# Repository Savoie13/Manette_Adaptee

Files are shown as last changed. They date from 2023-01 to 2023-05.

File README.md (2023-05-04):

# Manette Adaptée : Jouer sans limite
## Mathis Savoie et Jackob Breton
Ce répertoire GitHub est pour le projet de manette adapté avec l’école du Touret. Nous sommes 2 finissants en technologie de systèmes ordinés et le projet que nous allons tenter de réaliser est de programmer un Arduino Micro pour faire une manette pour des jeux Scratch. Cette manette adaptée permettra aux élèves de l’école du Touret qui ont moins de mobilité de jouer à des jeux vidéo comme leurs camarades. La manette sera composée de gros boutons et joysticks et permettra de brancher divers boutons pour plus de fonctionnalités. La manette comporte aussi un ESP8266 afin de pouvoir, grâce à une interface d’usager WEB, configurer la manette et ses boutons.
MicrosoftTeams-image

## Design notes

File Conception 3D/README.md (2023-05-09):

# Conception 3D
Ce dossier contient les fichiers de la conception 3D de la manette adaptée.
Le fichier Joystick_VFinale.stl est le fichier STL de la version finale du manche du joystick.
Le fichier Joystick_VFinale.gcode est le fichier gcode pour imprimer le joystick sur les imprimantes que
nous retrouvons au Cégep de Sherbrooke.

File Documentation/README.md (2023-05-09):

# Documentation
Ce dossier contient toute la documentation concernant le projet de manette adaptée.
Nous y retrouvons la documentation technique du projet, des PowerPoint de nos présentations orales, notre
participation au concours OsEntreprendre et des schémas que nous avons utilisés pour la documentation.

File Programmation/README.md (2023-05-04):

# Programmation
Ce dossier contient tous les programmes utiles au fonctionnement et à la conception de la manette adaptée. 
Aller voir le README.md dans les différents répertoires afin d'avoir plus d'information. 

Le programme dans le répertoire WriteEEPROM est le premier programme à télécharger dans l'arduino pro micro. Il permet d'installer la configuration par défaut dans l'EEPROM du pro micro.

Par la suite, il faut programmer la dernière version de Full_controllerV(x) dans l'arduino afin d'avoir le programme qui fait fonctionner la manette et réceptionne les JSON envoyé par l'ESP8266.

Le répertoire Code_Serveur_Spiffs contient le code Arduino IDE du L'ESP8266 ainsi que le répertoire "data" qui contient les fichiers nécéssaires pour le fonctionnement du serveur web.

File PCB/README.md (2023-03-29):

# PCB
Ce dossier contient les schémas et PCBs de la manette adaptée

Le répertoire Manette_JM contient le projet KiCad

Le répertoire Manette_JM_Gerber contient les fichiers Gerber afin de l'envoyer à une compagie de fabrication de PCB.

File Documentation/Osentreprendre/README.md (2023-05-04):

# Documentaiton Osentreprendre
C'est la documentation plus marketing du projet. Elle contient entre autre, une affiche de projet et une présentation PowerPoint.

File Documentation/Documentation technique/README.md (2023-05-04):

# Documentation technique
Partie technique de la documentation. Elle contient entre autres, le cahier des charges, le devis technique et le manuel technique

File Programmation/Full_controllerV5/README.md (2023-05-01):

# Full_controllerV5
Ce code est le programme principal du Arduino Pro Micro. Il sert à controller le clavier et la souris d'un ordinateur.
Il permet aussi au Arduino Pro Micro de recevoir des JSON sur son port série pour sa configuration, enregistrer 
ces configurations dans l'EEPROM et de les renvoyer en JSON sur son port série pour confirmer le tout.

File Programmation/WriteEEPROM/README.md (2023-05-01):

# WriteEEPROM
Code qui écrit des données dans l'EEPROM du Arduino Leonardo pour la configuration de base et le fonctionnement du code final full_controllerV5.

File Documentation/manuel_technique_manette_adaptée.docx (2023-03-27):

## Mettre Installation et Opération ensemble : Procédure d’utilisation

## Procédure d’installation

1. Placer la manette de la manière voulue près d’un ordinateur.
2. Brancher le câble USB de la manette dans l’ordinateur.
3. La manette est prête à être utilisé avec les paramètres déjà définis.

## Procédure d’opération

## Procédure de développement.

Voici ce qui est nécessaire pour le développement de la manette adaptée :

- Pour le développement du code du microcontrôleur :
1. Installer la dernière version d’Arduino IDE pour votre ordinateur (Windows, MacOs ou Linux) au site web suivant :

https://www.arduino.cc/en/software

2. Pendant l’installation, accepter toutes les configurations de base.
3. Ouvrir Arduino et créer un nouveau projet dans le menu : fichier > Nouveau.
4. Aller chercher le premier code au :

https://github.com/Savoie13/Manette_Adaptee/blob/main/Programmation/WriteEEPROM/WriteEEPROM.ino

5. Copier et coller ce code dans le nouveau projet et enregistrer ce projet n’importe où.
6. Brancher l’Arduino Leonardo.
7. Dans le menu : Outils > Type de carte : choisir Arduino Leonardo ETH.
8. Dans le menu : Outils > Port : choisir le port sur lequel est branché votre Arduino
9. Téléverser le code avec le bouton de la flèche en haut à gauche de la page. Le code devrait se télécharger en quelques secondes.
10. Maintenant le premier code téléchargé, il faut faire la même chose avec le deuxième code.
11. Refaire les étapes 3 à 9 inclusivement en utilisant le code à l’adresse suivante :

https://github.com/Savoie13/Manette_Adaptee/blob/main/Programmation/Full_controllerV5/Full_controllerV5.ino

12. Une fois ces deux codes téléchargés dans cet ordre les boutons et le joystick de la manette seront fonctionnels.
13. Toutes les informations nécessaires pour la compréhension et le développement des codes microcontrôleur de la manette adaptée sont inscrits dans l’entête de ce dernier. Le code est aussi commenté au complet pour comprendre la raison de la présence de chaque ligne dans ce dernier.
- Pour le développement du code site Web et point d’accès :

## Liste de matériel et coûts

Composants | Prix | Lien
- Microcontrôleur Micro Atmega32U4 | $15.49 | - Arduino Pro Micro (https://www.amazon.ca/ATmega32U4-Development-Microcontroller-Leonardo-Bootloader/dp/B07WPCLF8Y)
- Carte de développement WI-FI ESP8266 | $12.99 | - ESP8266 (https://addison-electronique.com/produits/pieces-et-composantes/electricite-electronique/genuino-electricite-electronique/carte-de-d-veloppement-wifi-mcu-esp8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)
- Joystick | $19.95 | - Joystick (https://www.digikey.ca/en/products/detail/adafruit-industries-llc/3102/6152821)
- 9 boutons de style arcade | $39.98 | - Boutons (https://www.amazon.ca/-/fr/boutons-poussoirs-lumineux-darcade-monnaie/dp/B01M7PNCO9)
- Boitier du joystick | $13.99 | - Boite joystick (https://www.amazon.ca/-/fr/LeMotech-imperm%C3%A9able-poussi%C3%A8res-%C3%A9lectriques-universels/dp/B075DJDT99)
- Boitier des boutons | $19.79 | - Boite boutons (https://www.amazon.ca/-/fr/LeMotech-imperm%C3%A9able-poussi%C3%A8res-%C3%A9lectriques-universels/dp/B075DJQJVY)
- PCB | $02.00 | - JLC PCB (https://jlcpcb.com/)
- Matériel électronique (connecteurs, fil, résistances, etc.) | $25.00

Total : $149.19

## Schéma électrique

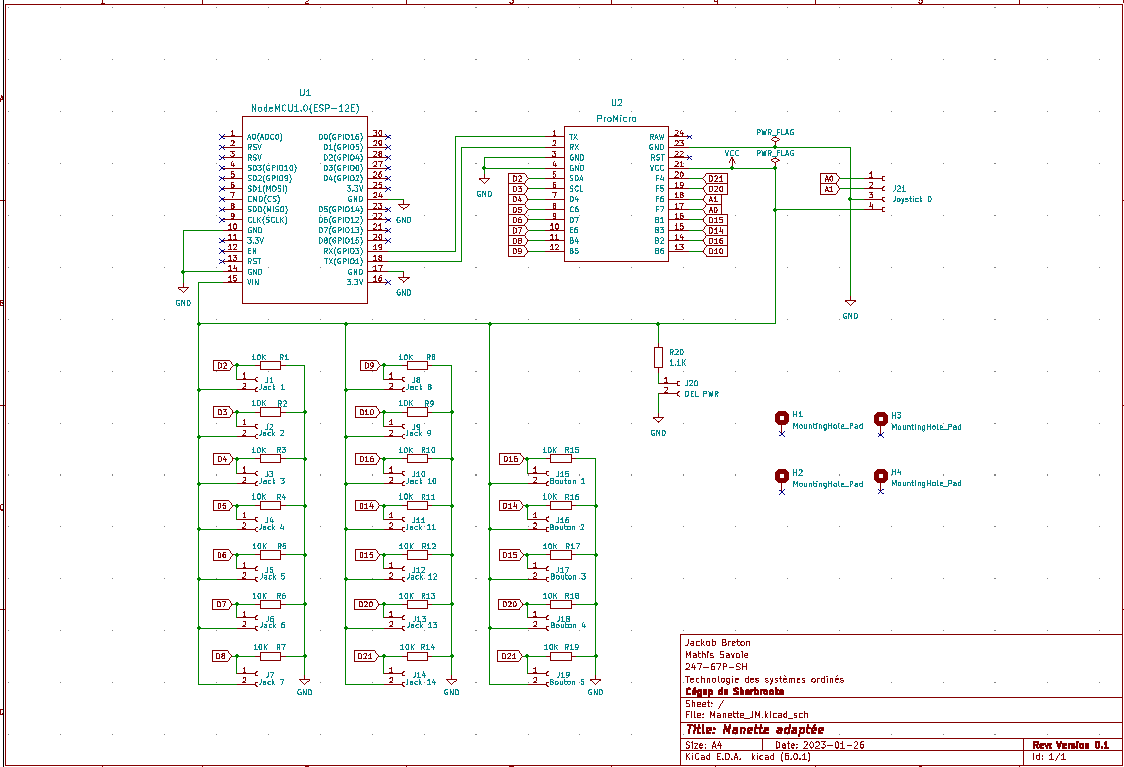
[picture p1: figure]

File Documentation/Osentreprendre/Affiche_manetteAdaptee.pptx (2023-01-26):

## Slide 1

Manette adaptée

JOUER SANS LIMITE

Projet pour l’école du Touret

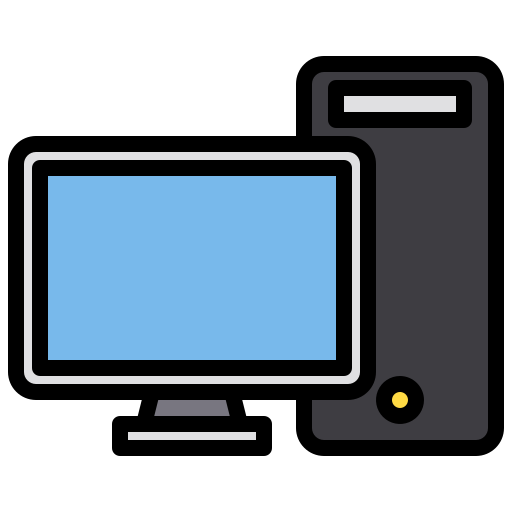
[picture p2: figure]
Pc - Free computer icons

Conçu pour les personnes avec une motricité réduite

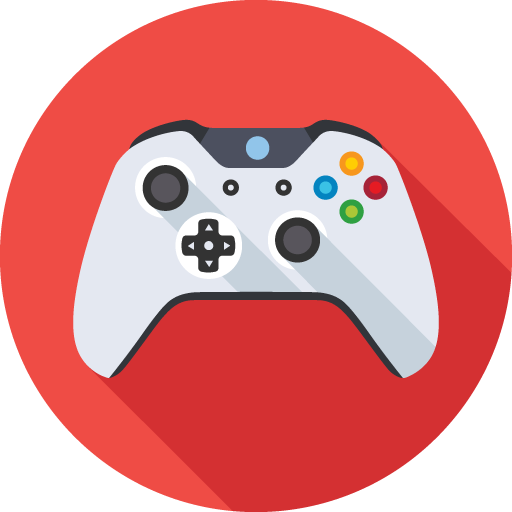
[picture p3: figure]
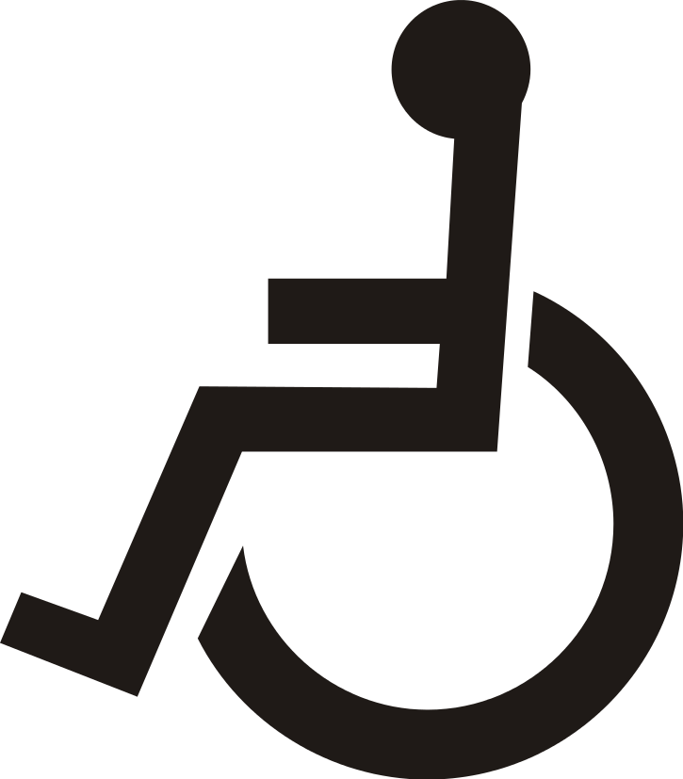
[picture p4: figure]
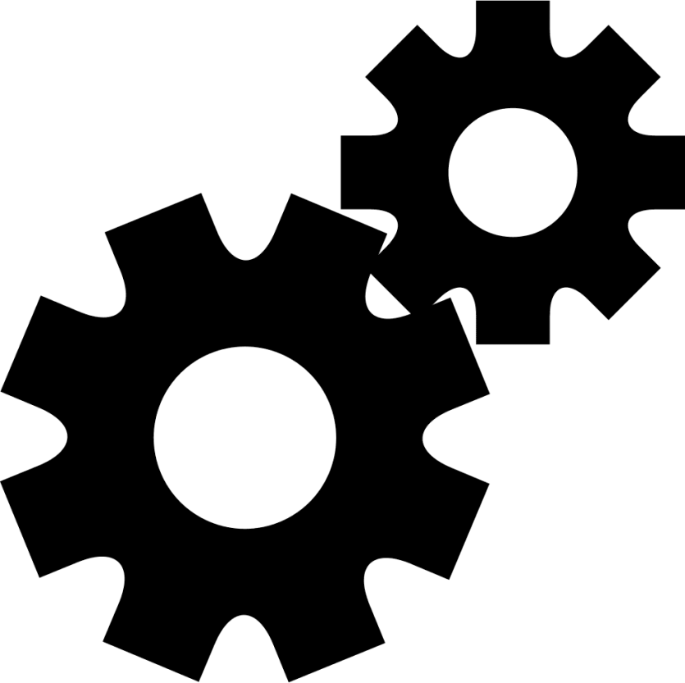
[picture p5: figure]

Configuration de la manette à l’aide d’une interface Web

Compatible PC

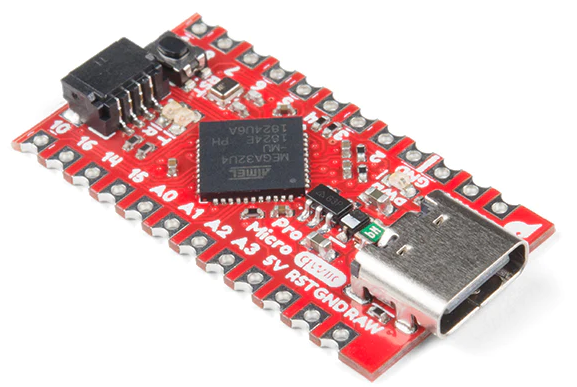
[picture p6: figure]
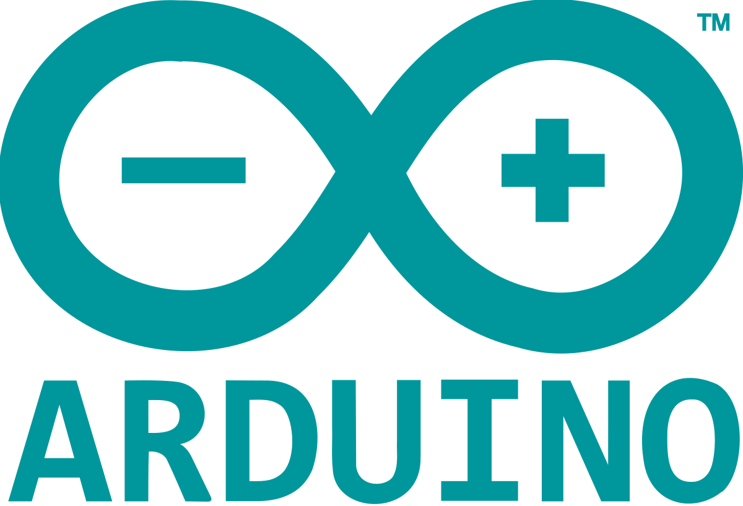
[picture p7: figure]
Arduino — Wikipédia
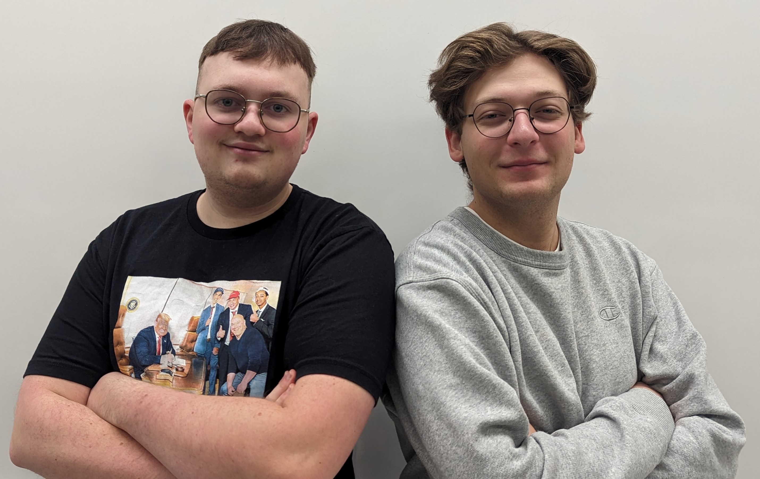
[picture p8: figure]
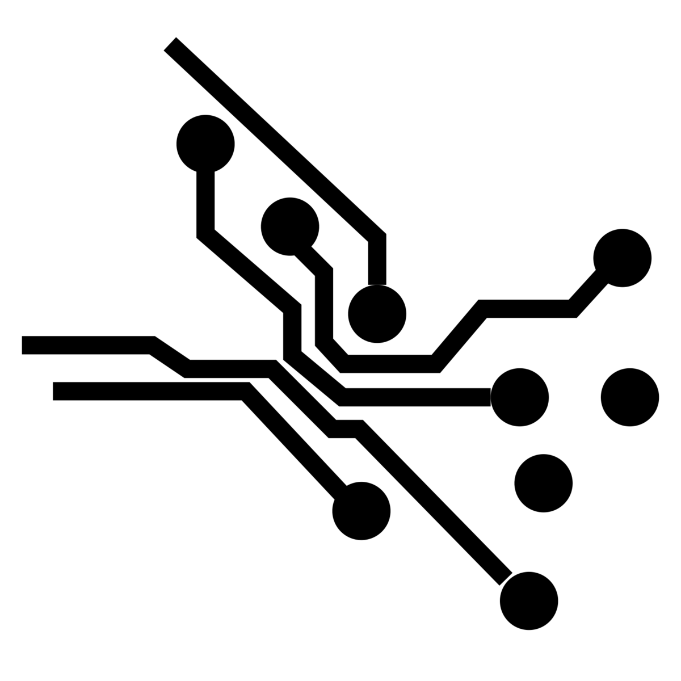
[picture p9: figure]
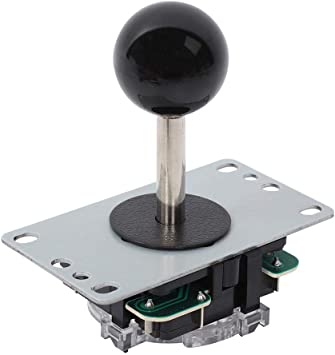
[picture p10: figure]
Manette USB pour PC, pour jeu d'arcade Jeu de combat simple Joystick Jeu de bricolage PC Pièces Machine Arcade Jeu Bouton et Joystick Simple Rocker pour Raspberry Pi), Zopsctg3irp8q4g-11 : Amazon.ca: Jeux
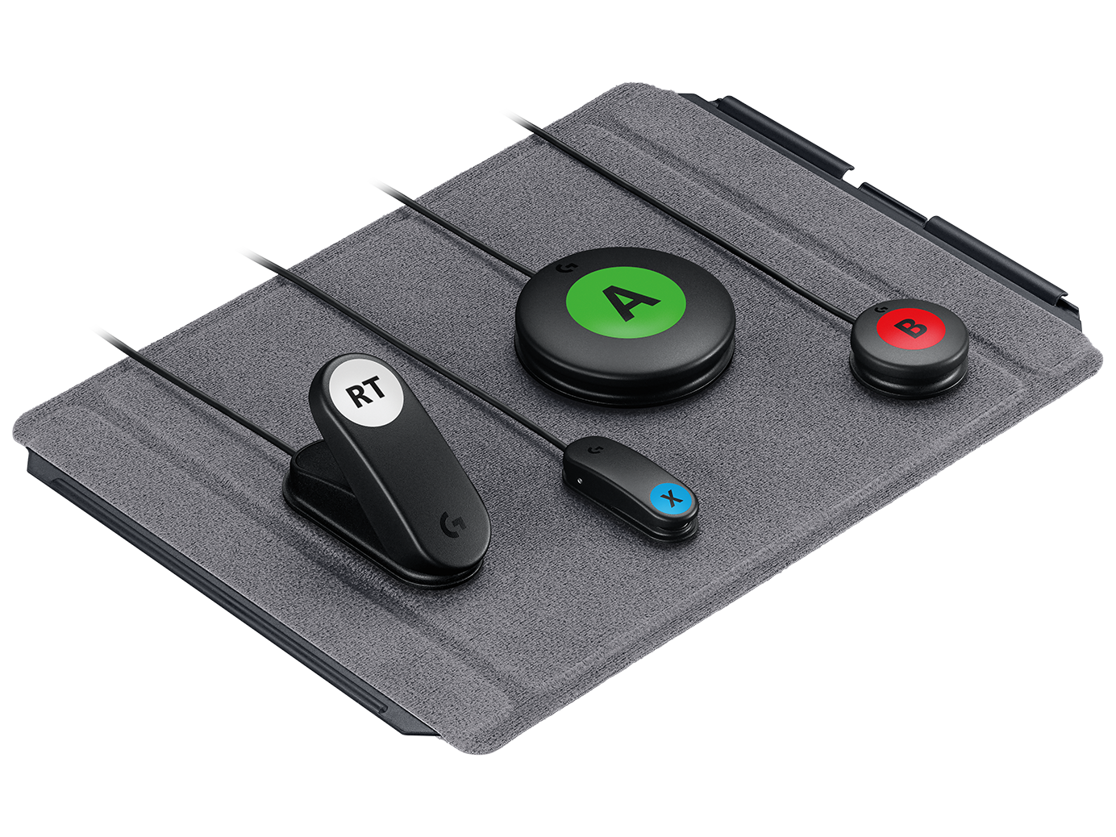
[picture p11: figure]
Kit de jeu Logitech G Adaptive pour la manette Xbox Adaptive

Jackob Breton

Mathis Savoie

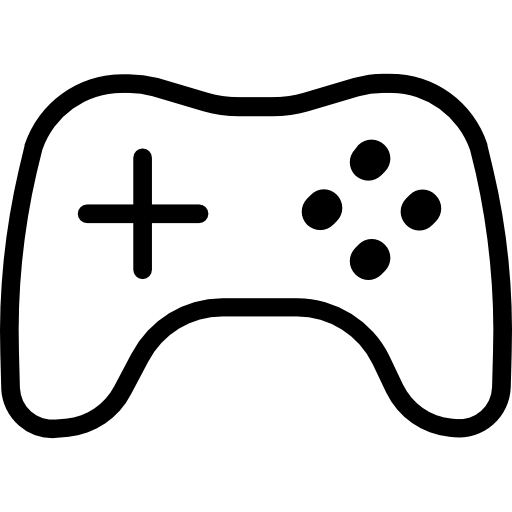
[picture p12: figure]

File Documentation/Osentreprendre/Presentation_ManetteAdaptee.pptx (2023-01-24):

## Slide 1

C’EST QUOI ?

MANETTE ADAPTÉE
JOUER SANS LIMITE

Présenté par Mathis Savoie et Jackob Breton

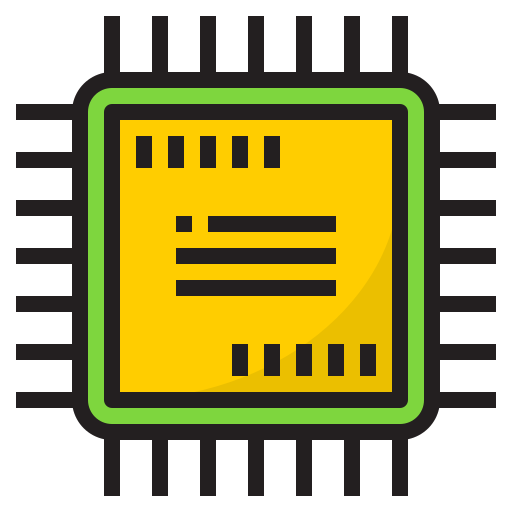
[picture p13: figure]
Processor - Free computer icons

- Rencontre avec le client
- Planification
- Conception du circuit électrique
- Sélection des empruntes
- Élaboration du circuit imprimé
- Envoie des fichiers de conception

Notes: JACKOB
Nos nom + génie électrique + nom du projet

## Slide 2

C’EST POUR QUI ?

C’EST QUOI ?

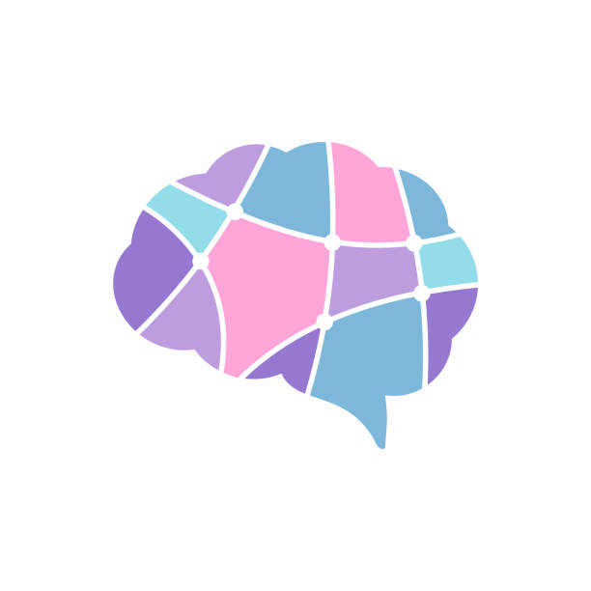
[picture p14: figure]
5,200 Intellectual Disability Illustrations & Clip Art - iStock
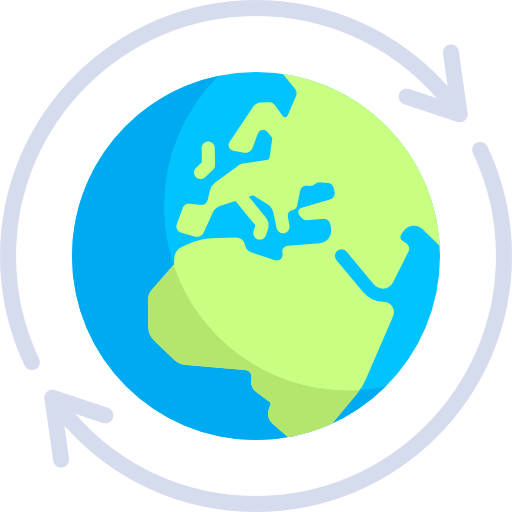
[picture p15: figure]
Worldwide - Free signs icons

MANETTE ADAPTÉE
JOUER SANS LIMITE

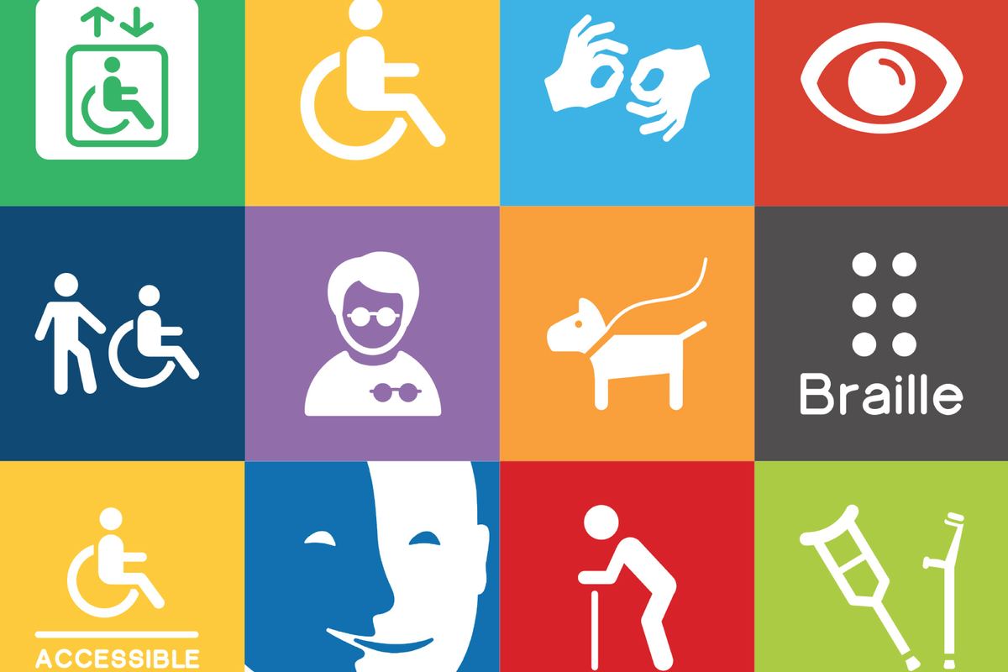
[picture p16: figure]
Différents types de handicaps - Département des Alpes-Maritimes

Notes: JACKOB
Manette adaptée pour les personnes avec difficulté motrice
Composé de gros boutons et joysticks de type arcade
Elle sera beaucoup plus grosse qu’une manette normal afin de facilité son utilisation

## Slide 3

C’EST QUOI ?

C’EST POUR QUI ?

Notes: MATHIS
- Les personnes ayant des déficiences motrices et/ou mentales qui donc manquent de dextérité et/ d’agilité
- //Mentales car elle ralentie les actions motrices (pense au mouvement avant de le faire)
- Quand même pour tous : enfants et adultes de partout dans le monde.
- Pour l’apprentissage et le développement, mais aussi pour leur inclusion avec les autres. (développer)

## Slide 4

COMMENT JOUER ?

LES ÉCOLES

PERSONNES À MOBILITÉ RÉDUITE

LES CENTRES ADAPTÉS

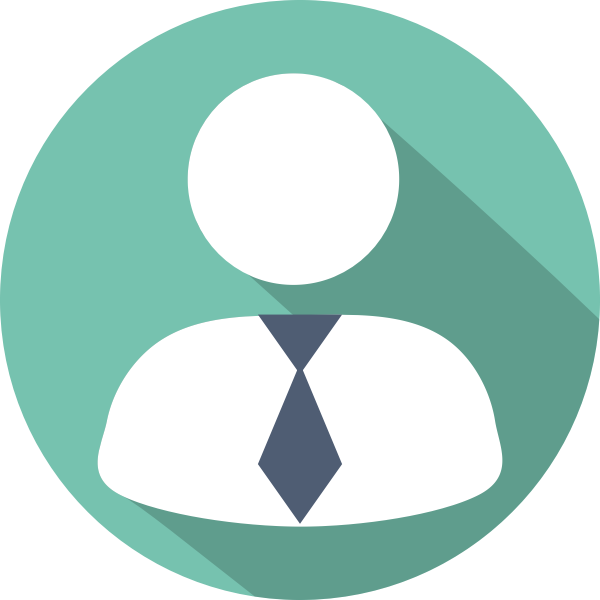
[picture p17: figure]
Client icon | Free SVG

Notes: MATHIS
- Suffit de brancher la manette dans un ordinateur pour l’utiliser.
- Pour plus d’options il sera possible de changer la configuration des boutons sur une application web.

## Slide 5

C’EST POUR QUI ?

NOS CLIENTS

Mini-ordinateur | 33$
Joystick | 32$
Boutons | 20$
Boîtier | 10$
Électronique | 35$
Total | 130$

LES ÉCOLES

PERSONNES À MOBILITÉ RÉDUITE

LES CENTRES ADAPTÉS

COMMENT JOUER ?

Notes: JACKOB
- Pour l’instant notre projet est en collaboration avec l’école du Touret (explique c’est quoi).
- Nos clients ciblés sont les personnes avec mobilité réduite.
- Par la suite, les écoles et les centres adaptés pour aidé à l’apprentissage des élèves handicapé.

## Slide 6

NOS CLIENTS

LES COÛTS

± 130$CAD
(équipements compris)

Mini-ordinateur | 33$
Joystick | 32$
Boutons | 20$
Boîtier | 10$
Électronique | 35$
Total | 130$

LES ÉCOLES

PERSONNES À MOBILITÉ RÉDUITE

LES CENTRES ADAPTÉS

130$CAD + taxes
(rien compris)

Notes: MATHIS

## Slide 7

130$CAD

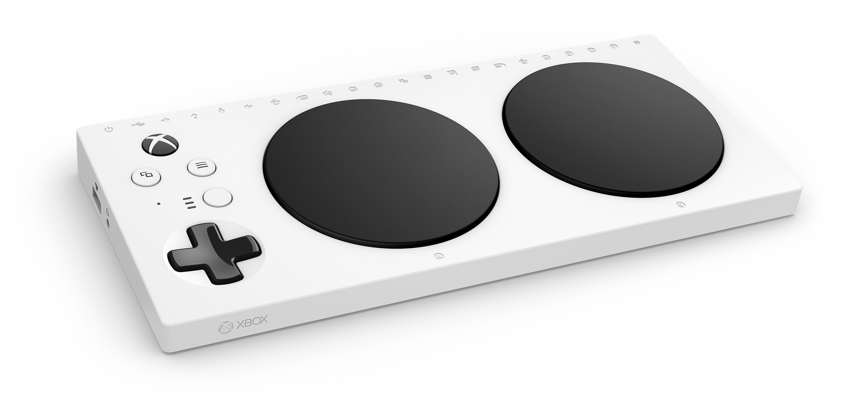
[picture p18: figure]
Xbox Adaptive Controller - Microsoft Store Canada

+

COMMENT JOUER ?

Une manette à besoin de minimum 12 boutons

± 130$CAD
(équipements compris)

130$CAD + taxes
(rien compris)

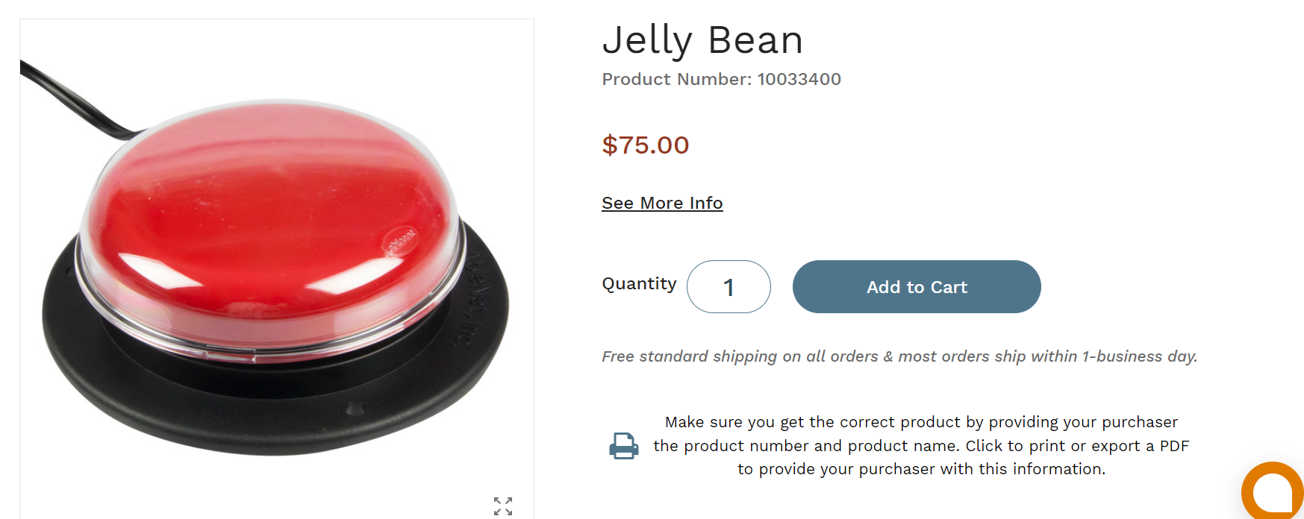
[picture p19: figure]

Mini-ordinateur | 33$
Joystick | 32$
Boutons | 20$
Boîtier | 10$
Électronique | 35$
Total | 130$

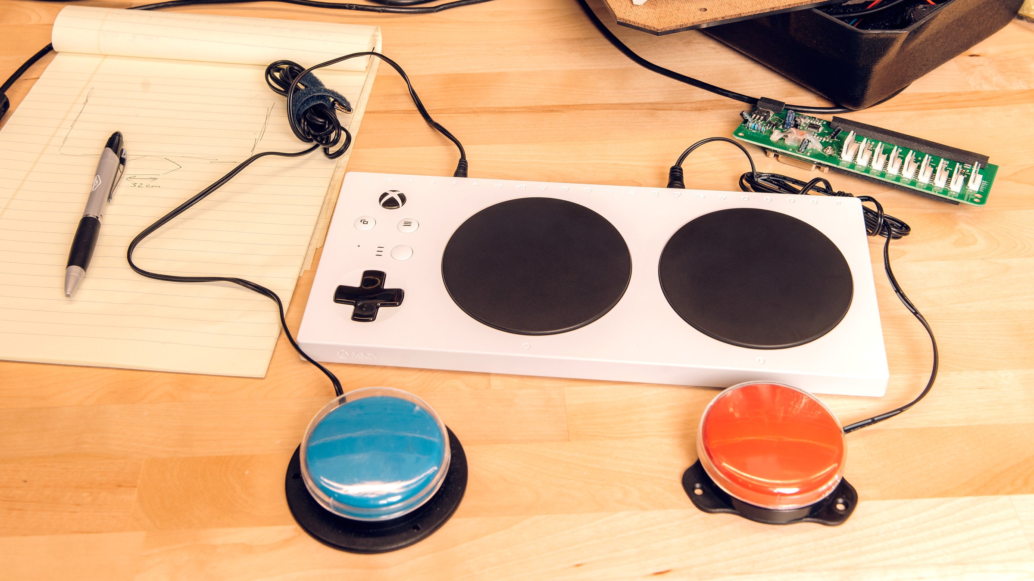
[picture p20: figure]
Microsoft's Xbox Adaptive Controller Gives Disabled Gamers a Power-Up | WIRED

MINIMUM
270$CAD
+ TAXES

100$CAD / ch.

+/ou

140$CAD
(ne convient pas à tous)
(Ne contient pas de joystick)

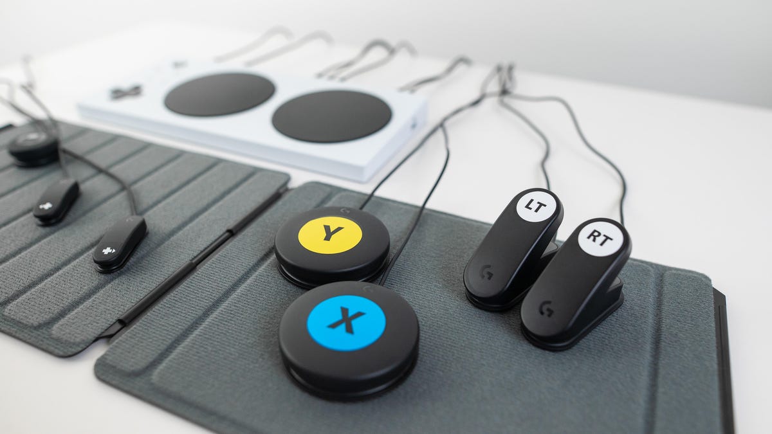
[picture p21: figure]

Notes: MATHIS
- Même prix que la concurrence (Microsoft), sauf que Microsoft inclus aucun boutons et joystick.

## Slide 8

130$CAD + taxes
(rien compris)

± 140$CAD
(tous compris)

Une manette à besoin de minimum 12 boutons

MINIMUM
270$CAD
+ TAXES

130$CAD

+

100$CAD / ch.

+/ou

140$CAD
(ne convient pas à tous)
(Ne contient pas de joystick)

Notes: JACKOB
- Pack à 140$ ne convient à tous, les boutons sont très petits et donc difficile pour personnes avec peu de dextérité.
- Pour des boutons plus adaptés comme l’école du Touret utilise, il faut ajouté 100$/boutons.
- De plus une manette de jeux utilise environ 12 boutons.
- Donc 270$ au minimum sans joystick et qui n’est pas nécessairement adapté pour tout le monde.

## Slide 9

130$CAD + taxes
(rien compris)

QUESTIONS ?

± 120$CAD
(tous compris)

130$CAD

Une manette à besoin de minimum 12 boutons

100$CAD / ch.

MINIMUM
270$CAD
+ TAXES

+/ou

140$CAD
(ne convient pas à tous)
(Ne contient pas de joystick)

+

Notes: JACKOB/MATHIS

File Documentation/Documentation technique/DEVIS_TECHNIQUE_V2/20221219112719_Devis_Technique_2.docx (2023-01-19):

Mathis Savoie, Jackob Breton

Technologies de systèmes ordinés

Groupe 2317

Devis technique du projet de l’école le Touret

Devis technique présenté à

M. Nicolas Huppé

Pour le cours

Planification de projet 247-575-SH A2022

Remis

22 novembre 2022

# Mise en contexte

Ce devis technique est pour le projet de manette adapté avec l’école du Touret. Nous sommes 2 finissants en technologie de systèmes ordinés et le projet que nous allons tenter de réaliser est de programmer un Arduino Micro pour faire une manette pour des jeux Scratch. Cette manette adaptée permettrait aux élèves de l’école du Touret qui ont moins de mobilité de jouer à des jeux vidéo comme leurs camarades. La manette sera composée de gros boutons et joysticks et permettra de brancher divers boutons pour plus de fonctionnalités. La manette comporterait aussi un ESP-32 afin de pouvoir, grâce à une interface d’usager WEB, configurer la manette et ses boutons.

# Schéma synoptique

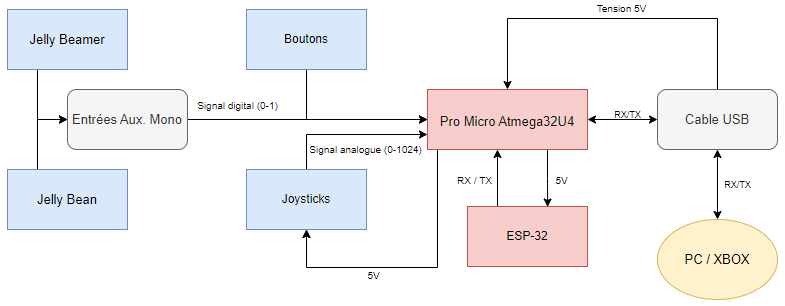
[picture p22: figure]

Figure 1 : Schéma synoptique

Le système est composé de :

- Une carte de développement Pro Micro ATmega32U4 pour Arduino
- 10 entrées auxiliaires mono. Afin d’utiliser le Jelly Beamer ainsi que le Jelly Bean (Boutons externes)
- 5 boutons internes ainsi que 2 joysticks
- Une alimentation externe (elle sera nécessaire selon les joysticks utilisés et pour une possible utilisation sans fil)
- Un ESP-32
- Une sortie USB

Notre carte de développement Pro Micro ATmega32U4 pour Arduino nous permettra d’utiliser plus facilement la fonctionnalité d’utiliser les boutons et les joysticks comme un clavier et une souris grâce au H.I.D. (human interface device) qui est un protocole permettant l’interaction entre l’ordinateur et un humain avec des claviers, souris, joyticks, etc. La carte de développement comprend plusieurs entrées/sorties, ce qui nous permettra de brancher plusieurs boutons afin de simuler une manette. Les entrées auxiliaires et les boutons seront branchés dans des entrées digitales alors que les joysticks seront branchés dans des entrées analogiques. L’ESP-32 sera utilisé en point d’accès afin de configurer l’ATmega32U4 à partir d’un serveur web et pour avoir une interface simple pour l’usager.

L’alimentation du système reposera entièrement sur l’alimentation 5V fournie par la connexion USB.

Nous utiliserons l’application Arduino IDE afin de faire notre programme puisque l’ATmega32U4 est compatible avec Arduino.

# Prototype

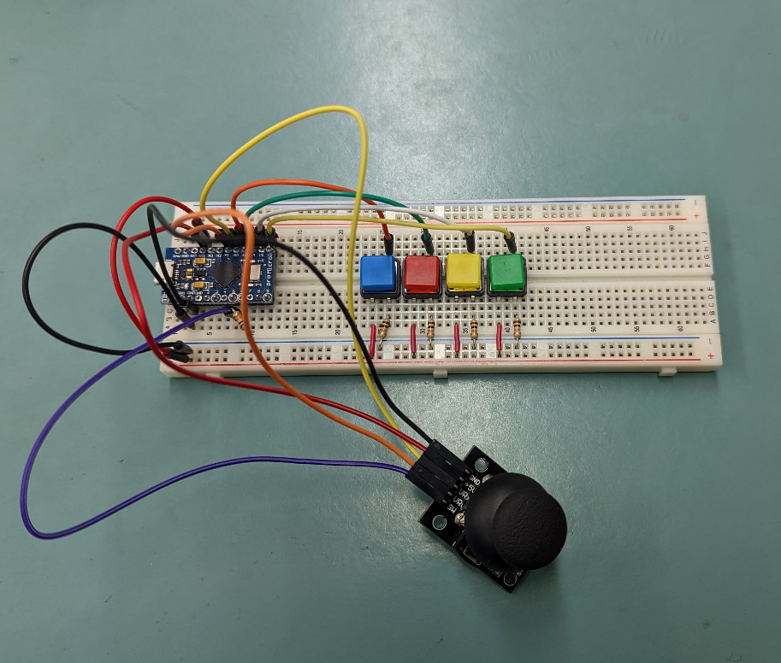
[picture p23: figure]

Figure 2 : Prototype

Notre premier prototype nous permet de contrôler une souris d’ordinateur et son clic gauche avec un joystick. Les 4 boutons nous permettent aussi de simuler quatre touches de claviers. Cela nous permet de confirmer l’efficacité du « H.I.D » l’ATmega32U4 pour le joystick.

# Défis techniques/risques

- Configuration de la carte de développement Pro Micro ATmega32U4 à partir du point d’accès de l’ESP-32.
- Conception des pièces imprimées en 3D comme le support du joystick et des boutons de style arcade.

# Schémas électriques

## Branchement de l’ESP sur la carte de développement Pro Micro ATmega32U4

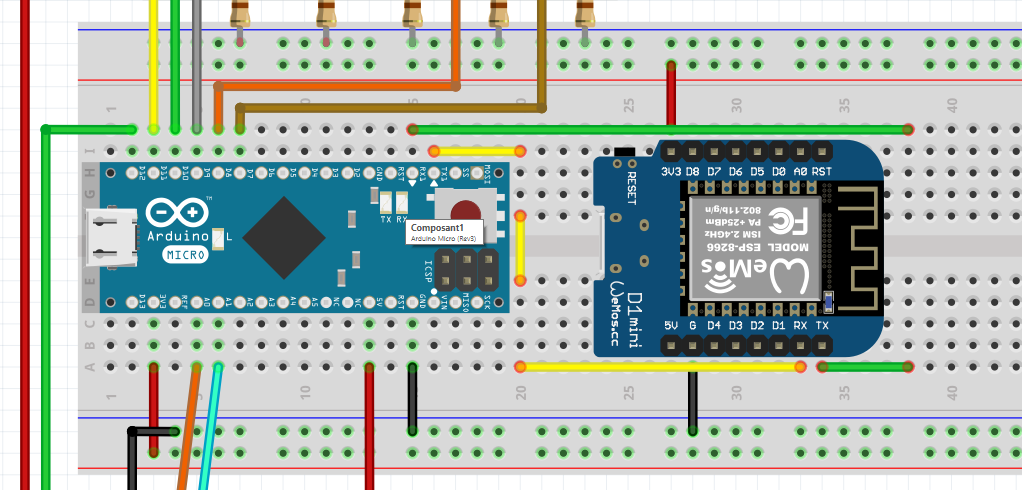
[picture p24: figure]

Figure 3 : ESP-01/Arduino

## Branchement du joystick sur la carte de développement Pro Micro ATmega32U4


Figure 4 : Joystick/Arduino

## Branchement des boutons sur la carte de développement Pro Micro ATmega32U4


Figure 5 : Boutons/Arduino

# Évaluation des coûts

Composants | Prix | Lien
Micro Atmega32U4 | 15,39$ | - Arduino Pro Micro (https://cegepdesherbrooke.sharepoint.com/sites/247-575-SHPLANIFICATIONDEPROJET-LeTouret/Documents%20partages/Le%20Touret/Bootloader/dp/B07WPCLF8Y)
ESP-32 | 17,79$ | - ESP-32 (https://www.amazon.ca/ESP-WROOM-32-d%C3%A9veloppement-Bluetooth-Microcontr%C3%B4leur-Processeur/dp/B07H2SM695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)
Joysticks | 31,02$ | - Joystick (https://www.digikey.ca/en/products/detail/adafruit-industries-llc/3102/6152821?productid=6152821)
Boutons de style arcade | 19,99$/5 | - Boutons (https://www.amazon.ca/-/fr/Starts-boutons-poussoirs-lumineux-darcade/dp/B01M7PNCO9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)
Filament pour impression 3D | ~20$
PCB | ~10$

Total: 114.19$

# Échéancier


Figure 6 : Échéancier

# Interface usager

L’interface usager permettra de configurer les boutons connectés à l'ATmega32U4 afin de simuler une autre touche du clavier que celle assignée de base par le programme. Par exemple, les boutons 1 à 4 sont assignés aux touches 'W', 'A', 'S’et 'D’et l'usager pourra les configurer afin qu'ils soient assignés aux touches '1', '2', '3' et '4'. Il pourrait annuler les modifications ou enregistrer les modifications. Cette interface se retrouvera sur un fureteur Web.


Figure 7 : Interface usager

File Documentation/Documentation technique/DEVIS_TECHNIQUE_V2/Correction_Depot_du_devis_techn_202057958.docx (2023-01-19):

Mathis Savoie, Jackob Breton

Technologies de systèmes ordinés

Groupe 2317

Devis technique du projet de l’école le Touret

Devis technique présenté à

M. Nicolas Huppé

Pour le cours

Planification de projet 247-575-SH A2022

Remis

# Mise en contexte

Ce devis technique est pour le projet de manette adaptée avec l’école du Touret. Nous sommes 2 finissants en technologie de systèmes ordinés et le projet que nous allons tenter de réaliser est de programmer un Arduino Micro pour faire une manette pour des jeux Scratch. Cette manette adaptée permettrait aux élèves de l’école du Touret qui ont moins de mobilité de jouer à des jeux vidéo comme leurs camarades. La manette seraserait composée de gros boutons et joysticks et permettra de brancher divers boutons pour plus de fonctionnalités. La manette comporterait aussi un ESP-32 afin de pouvoir, grâce à une interface d’usager WEB, de configurer la manette et ses boutons.

# Schéma synoptique


Figure 1 : Schéma synoptique

Le système est composé de :

- Une carte de développement Pro Micro ATmega32U4 pour Arduino
- 10 ! ok entrées auxiliaires mono. Afin d’utiliser le Jelly Beamer ainsi que le Jelly Bean (Boutons externes)
- 5 boutons internes ainsi que 2 joysticks
- Une alimentation externe (elle sera nécessaire selon les joysticks utilisés et pour une possible utilisation sans fil)
- Un ESP-32
- Une sortie USB

Notre carte de développement Pro Micro ATmega32U4 pour Arduino nous permettra d’utiliser plus facilement la fonctionnalité d’utiliser les boutons et les joysticks comme un clavier et une souris grâce au H.I.D. (human interface device) qui est un protocole permettant l’interaction entre l’ordinateur et un humain avec des claviers, souris, joyticks, etc. La carte de développement comprend plusieurs entrées/sorties, ce qui nous permettra de brancher plusieurs boutons afin de simuler une manette. Les entrées auxiliaires et les boutons seront branchés dans des entrées digitales alors que les joysticks seront branchés dans des entrées analogiques. L’ESP-32 sera utilisé en point d’accès ok afin de configurer l’ATmega32U4 à partir d’un serveur web et pour avoir une interface simple pour l’usager.

L’alimentation du système reposera entièrement sur l’alimentation 5V fournie par la connexion USB.

Nous utiliserons l’application Arduino IDE afin de faire notre programme puisque l’ATmega32U4 est compatible avec Arduino.

# Prototype


Figure 2 : Prototype

Notre premier prototype nous permet de contrôler une souris d’ordinateur et son clic gauche avec un joystick. Les 4 boutons nous permettent aussi de simuler quatre touches de claviers. Cela nous permet de confirmer l’efficacité du « H.I.D » l’ATmega32U4 pour le joystick.

# Défis techniques/risques

- Configuration de la carte de développement Pro Micro ATmega32U4 à partir du point d’accès de l’ESP-32.
- Conception des pièces imprimées en 3D comme le support du joystick et des boutons de style arcade.

# Schémas électriques Comme dans la version 1. Il faut une explication sommaire de ces circuits.

## Branchement de l’ESP sur la carte de développement Pro Micro ATmega32U4


Figure 3 : ESP-01/Arduino

## Branchement du joystick sur la carte de développement Pro Micro ATmega32U4


Figure 4 : Joystick/Arduino

## Branchement des boutons sur la carte de développement Pro Micro ATmega32U4


Figure 5 : Boutons/Arduino

# Évaluation des coûts

Composants | Prix | Lien
Micro Atmega32U4 | 15,39$ | - Arduino Pro Micro (https://cegepdesherbrooke.sharepoint.com/sites/247-575-SHPLANIFICATIONDEPROJET-LeTouret/Documents%20partages/Le%20Touret/Bootloader/dp/B07WPCLF8Y)
ESP-32 | 17,79$ | - ESP-32 (https://www.amazon.ca/ESP-WROOM-32-d%C3%A9veloppement-Bluetooth-Microcontr%C3%B4leur-Processeur/dp/B07H2SM695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)
Joysticks | 31,02$ | - Joystick (https://www.digikey.ca/en/products/detail/adafruit-industries-llc/3102/6152821?productid=6152821)
Boutons de style arcade | 19,99$/5 | - Boutons (https://www.amazon.ca/-/fr/Starts-boutons-poussoirs-lumineux-darcade/dp/B01M7PNCO9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)
Filament pour impression 3D | ~20$
PCB | ~10$ ++
10 ports jack 1/8 ??

Total: 114.19$

# Échéancier


Figure 6 : Échéancier

# Interface usager

L’interface usager permettra de configurer les boutons connectés à l'ATmega32U4 afin de simuler une autre touche du clavier que celle assignée de base par le programme. Par exemple, les boutons 1 à 4 sont assignés aux touches 'W', 'A', 'S’et 'D’et l'usager pourra les configurer afin qu'ils soient assignés aux touches '1', '2', '3' et '4'. Il pourrait annuler les modifications ou enregistrer les modifications. Cette interface sera accessible à l’aide un fureteur Web. Avez-vous une idée de la méthode utilisée pour construire ce interface et retourner l’information au esp ?


Figure 7 : Interface usager

- Présentation, propreté, mise en page (respect des normes méthodologiques, numérotation, images, alignement, page titre, table des matières, etc.) | 9/10
- Qualité de l'expression française (orthographe, structure de l'écriture, cohérence de l'écriture) | 16/20
- Présentation de la solution : Mise en contexte et rappel des objectifs du cahier des charges. Schéma synoptique et texte explicatif. Prototypes validant la proposition. Défis et Risques identifiés. | 35/40
- Schéma électrique Explication sommaire des schéma | 7.5/10
- Évaluation des coûts | 4/5
- Échéancier pour session H2023 | 4/5
- Interface usager | 8/10
Total: | 83.5/100

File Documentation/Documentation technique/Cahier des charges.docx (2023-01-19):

# Cahier des charges

# Hub pour utiliser les appareils électroniques de l’école Touret

Jackob Breton

Mathis Savoie

# Mise en contexte

L’école du Touret est une école spécialisée en déficience intellectuelle moyenne à profonde, le retard global de développement important et la présence possible de certains troubles associés. L’école se situe dans la ville de Sherbrooke.

Les élèves de l’école du Touret ont besoin d’une équipe spécialisée, des programmes éducatifs adaptés ainsi qu’un encadrement spécialisé pour favoriser leurs développements. Les équipements disponibles sur le marché ne conviennent pas au besoin de l’école et c’est pour cela qu’un équipement favorisant la communication aiderait l’interaction et le développement des élèves. Cet équipement va aussi aider à l’inclusion des élèves dans les différents groupes de l’école.

# Objectifs du projet

Le projet est un système qui permet l’utilisation des différents boutons et interrupteurs afin de contrôler divers objets interactifs tels que des lumières, des boites à son, des jouets ou même un jeu vidéo. Le système comportera différentes configurations selon les besoins de chaque élève. Chaque élève aura un module propre à lui afin de simplifier son utilisation et sa configuration.


# Portée du projet

Ce projet est prévu pour être installé et mis en route directement chez le client. Les prototypes seront fonctionnels et utilisables par le client.

# Besoins et Contrainte liés au projet

## Besoins

Les élèves de l’école du Touret ont de la difficulté à communiquer et interagir avec leur environnement de tous les jours. C’est pourquoi notre système doit répondre à des besoins précis qui faciliteraient leur quotidien et leur donneraient une certaine autonomie.

### Quantitatif (mesurable)

- 1 module par élève.

### Qualitatif / fonctionnalité

- Active et désactive des jouets, des lumières, des boites à sons, etc.
- Utilise plusieurs ports de communication.
- Portable.
- Tiens seul, pas besoin d’être tenu par l’élève ou l’éducateur/éducatrice.
- Est adapté et configuré pour chaque élève individuellement.
- Fonctionnel avec l’équipement déjà utilisé par le client.

## Contraintes

Les élèves de l’école du Touret impliqués par le projet ont des déficiences intellectuelles sévères où ils ont l’âge cognitif d’un enfant allant de 6 mois à 7 ans. C’est pour cela que notre système doit être sécuritaire pour les jeunes enfants.

### Matérielles :

- Module solide
- Module robuste
- Le processeur doit être compatible avec Arduino IDE
- Pas de lumière clignotante (épilepsie)
- Pas de petites pièces

### Logicielles :

- Le module sera configurable
- Arduino IDE
- Les logiciels doivent être accessibles par la commission scolaire (plusieurs applications bloquées)

# Résultats attendus, exigences du projet.

## Résultats attendus :

Un module de contrôle d’entrée et sortie par élèves qui leur permet de communiquer et interagir avec leur environnement. Les modules seront programmés différemment pour chaque élève individuellement selon leurs besoins. Les modules seront remis déjà programmé par nous et seront prêts à être utilisés.

## Exigences

L’installation et la mise en route du projet seront la responsabilité des employés de l’école du Touret qui auront été formés pour le faire. La modification des configurations sera faite par nous et ne sera pas accessible par le client.

# Documentation de projet

https://cegepdesherbrooke-my.sharepoint.com/:f:/g/personal/nicolas_huppe_cegepsherbrooke_qc_ca/En2USrMrg6JBmYM9yETiKM4BNVWNWCdtl5KvYZu4piy1FQ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

https://cegepdesherbrooke-my.sharepoint.com/:w:/g/personal/nicolas_huppe_cegepsherbrooke_qc_ca/EQcwyw2nMJZIihJd9RLA4x4Bj6ZfDT8CHDjCVKMcudHqYQ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

https://cegepdesherbrooke-my.sharepoint.com/:w:/g/personal/nicolas_huppe_cegepsherbrooke_qc_ca/ERdgSr2jLlRPvmZwwQQgw5IBzEYZTmknvO6R5kPFDmvCSg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

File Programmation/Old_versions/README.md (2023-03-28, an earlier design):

# Old_versions
Ce dossier contient les anciennes versions des programme de la manette adaptée. Ils ne sont pas à jours.

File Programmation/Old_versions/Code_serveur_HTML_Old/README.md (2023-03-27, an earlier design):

# Code HTML / Javascript
Ce répertoire contient le code HTML, le code Javascript, le code CSS, le fichier de configuration du point d'accès de l'ESP8266 et une image (.png) qui est utilisé dans le serveur web.
Il est important de supprimer les anciens fichiers avant de mettre les fichiers présents dans ce répertoire. 

Pour notre part, nous utilisons FileZilla afin de nous connecter à l'ESP et avoir accès aux fichiers du serveur.
Hôte (IP): 192.168.4.1, User : jmer, mot de passe : 123

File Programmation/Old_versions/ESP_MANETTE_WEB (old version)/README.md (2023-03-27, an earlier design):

# ESP8266
Ce répertoire contient le dossier pour installer le code de l'ESP à partir de flashdownloadtool et il contient le dossier où nous retrouvons les fichiers du serveur WEB.

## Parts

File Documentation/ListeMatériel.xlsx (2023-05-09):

Nom des composants | Numéro de pièce | Description | Lien web | Prix unitaire ($) | Quantité | Total ($)
Arduino Pro Micro | ‎KYES8-196-1-CA | Microcontroleur basé sur ATmega32U4 | Arduino Pro Micro (https://www.amazon.ca/ATmega32U4-Development-Microcontroller-Leonardo-Bootloader/dp/B07WPCLF8Y) | 15.97 | 1 | 15.97
NodeMCU ESP8266 |  | Microcontrôleur avec connexion Wi-Fi | ESP8266 (https://addison-electronique.com/produits/pieces-et-composantes/electricite-electronique/genuino-electricite-electronique/carte-de-d-veloppement-wifi-mcu-esp8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) | 12.99 | 1 | 12.99
Joystick 3102 | 1528-1722-ND | Joystick analogique 2 axes | Joystick (https://www.digikey.ca/en/products/detail/adafruit-industries-llc/3102/6152821) | 19.95 | 1 | 19.95
Boutons | ‎EG-5/60MM-TM-BUT | Paquet de 5 boutons de style arcade | Boutons (https://www.amazon.ca/-/fr/boutons-poussoirs-lumineux-darcade-monnaie/dp/B01M7PNCO9) | 19.99 | 2 | 39.98
Boitier du joystick | lm201709071386 | Boitier en ABS pour contenir le joystick de la manette. 3,9" x 3,9" x 2,8" | Boite joystick (https://www.amazon.ca/-/fr/LeMotech-imperm%C3%A9able-poussi%C3%A8res-%C3%A9lectriques-universels/dp/B075DJDT99) | 13.99 | 1 | 13.99
Boitier des boutons | ‎lmus-whtbox-202080 | Boitier en ABS pour contenir les boutons et l'électronique de la manette. 7,9" x 7,9" x 3,9" | Boite boutons (https://www.amazon.ca/-/fr/LeMotech-imperm%C3%A9able-poussi%C3%A8res-%C3%A9lectriques-universels/dp/B075DJQJVY) | 22.99 | 1 | 22.99
PCB |  | Circuit imprimé pour la soudure et la connexion des différents composants de la manette | JLC PCB (https://jlcpcb.com/) | 52 | 1 | 52
Matériel électronique |  | Résistances, fil, connecteurs JST-xh, vis, etc.. |  | 25 | 1 | 25
 |  |  |  |  | Sous-total | 202.87
 |  |  |  |  | Taxes | 30.38
 |  |  |  |  | Grand total | 233.25

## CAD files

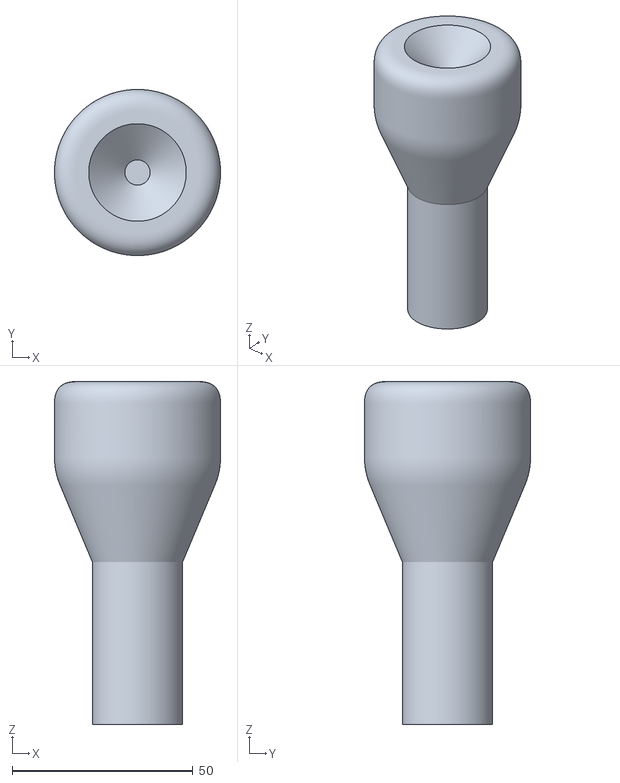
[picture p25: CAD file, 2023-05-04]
Conception 3D/Joystick_VFinale.stl
46.0 x 46.0 x 95.0

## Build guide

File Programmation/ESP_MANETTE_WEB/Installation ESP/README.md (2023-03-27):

# Installation de l'ESP8266
Ce dossier contient tous les fichers pour installer la configuration de l'ESP8266 avec flashdownloadtool

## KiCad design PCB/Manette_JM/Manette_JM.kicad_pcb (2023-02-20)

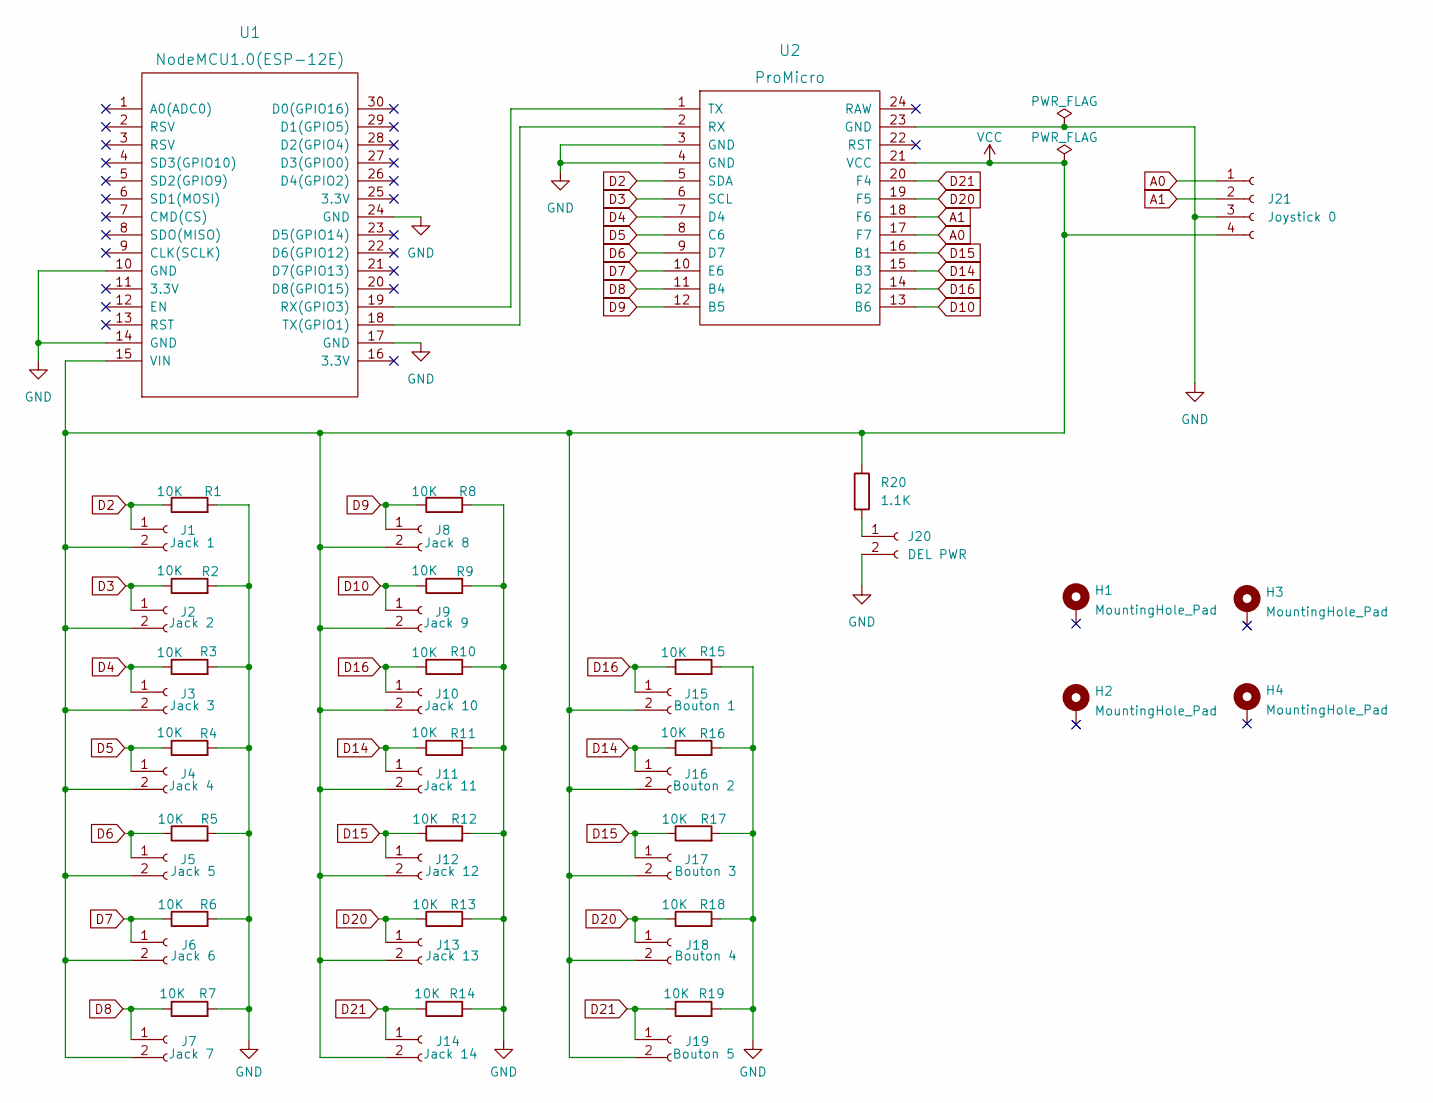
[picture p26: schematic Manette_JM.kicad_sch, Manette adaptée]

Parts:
H1, H2, H3, H4: MountingHole_Pad; MountingHole_3.2mm_M3_Pad_Via
J1: Jack 1; PinHeader_1x02_P2.54mm_Vertical
J2: Jack 2; PinHeader_1x02_P2.54mm_Vertical
J3: Jack 3; PinHeader_1x02_P2.54mm_Vertical
J4: Jack 4; PinHeader_1x02_P2.54mm_Vertical
J5: Jack 5; PinHeader_1x02_P2.54mm_Vertical
J6: Jack 6; PinHeader_1x02_P2.54mm_Vertical
J7: Jack 7; PinHeader_1x02_P2.54mm_Vertical
J8: Jack 8; PinHeader_1x02_P2.54mm_Vertical
J9: Jack 9; PinHeader_1x02_P2.54mm_Vertical
J10: Jack 10; PinHeader_1x02_P2.54mm_Vertical
J11: Jack 11; PinHeader_1x02_P2.54mm_Vertical
J12: Jack 12; PinHeader_1x02_P2.54mm_Vertical
J13: Jack 13; PinHeader_1x02_P2.54mm_Vertical
J14: Jack 14; PinHeader_1x02_P2.54mm_Vertical
J15: Bouton 1; PinHeader_1x02_P2.54mm_Vertical
J16: Bouton 2; PinHeader_1x02_P2.54mm_Vertical
J17: Bouton 3; PinHeader_1x02_P2.54mm_Vertical
J18: Bouton 4; PinHeader_1x02_P2.54mm_Vertical
J19: Bouton 5; PinHeader_1x02_P2.54mm_Vertical
J20: DEL PWR; PinHeader_1x02_P2.54mm_Vertical
J21: Joystick 0; PinHeader_1x04_P2.54mm_Vertical
R1, R2, R3, R4, R5, R6, R7, R8, R9, R10, R11, R12, R13, R14, R15, R16, R17, R18, R19: 10K; R_0805_2012Metric_Pad1.20x1.40mm_HandSolder
R20: 1.1K; R_0805_2012Metric_Pad1.20x1.40mm_HandSolder
U1: NodeMCU1.0(ESP-12E); NodeMCU-LoLinV3
U2: ProMicro

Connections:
A0: J21.1, U2.17 (F7)
A1: J21.2, U2.18 (F6)
D2: J1.1, R1.1, U2.5 (SDA)
D3: J2.1, R2.1, U2.6 (SCL)
D4: J3.1, R3.1, U2.7 (D4)
D5: J4.1, R4.1, U2.8 (C6)
D6: J5.1, R5.1, U2.9 (D7)
D7: J6.1, R6.1, U2.10 (E6)
D8: J7.1, R7.1, U2.11 (B4)
D9: J8.1, R8.1, U2.12 (B5)
D10: J9.1, R9.1, U2.13 (B6)
D14: J11.1, J16.1, R11.1, R16.1, U2.15 (B3)
D15: J12.1, J17.1, R12.1, R17.1, U2.16 (B1)
D16: J10.1, J15.1, R10.1, R15.1, U2.14 (B2)
D20: J13.1, J18.1, R13.1, R18.1, U2.19 (F5)
D21: J14.1, J19.1, R14.1, R19.1, U2.20 (F4)
GND: J20.2, J21.3, R1.2, R2.2, R3.2, R4.2, R5.2, R6.2, R7.2, R8.2, R9.2, R10.2, R11.2, R12.2, R13.2, R14.2, R15.2, R16.2, R17.2, R18.2, R19.2, U1.10 (GND), U1.14 (GND), U1.17 (GND), U1.24 (GND), U2.3 (GND), U2.4 (GND), U2.23 (GND)
unnamed: J20.1, R20.2
unnamed: U1.18 (TX(GPIO1)), U2.2 (RX)
unnamed: U1.19 (RX(GPIO3)), U2.1 (TX)
VCC: J1.2, J2.2, J3.2, J4.2, J5.2, J6.2, J7.2, J8.2, J9.2, J10.2, J11.2, J12.2, J13.2, J14.2, J15.2, J16.2, J17.2, J18.2, J19.2, J21.4, R20.1, U1.15 (VIN), U2.21 (VCC)

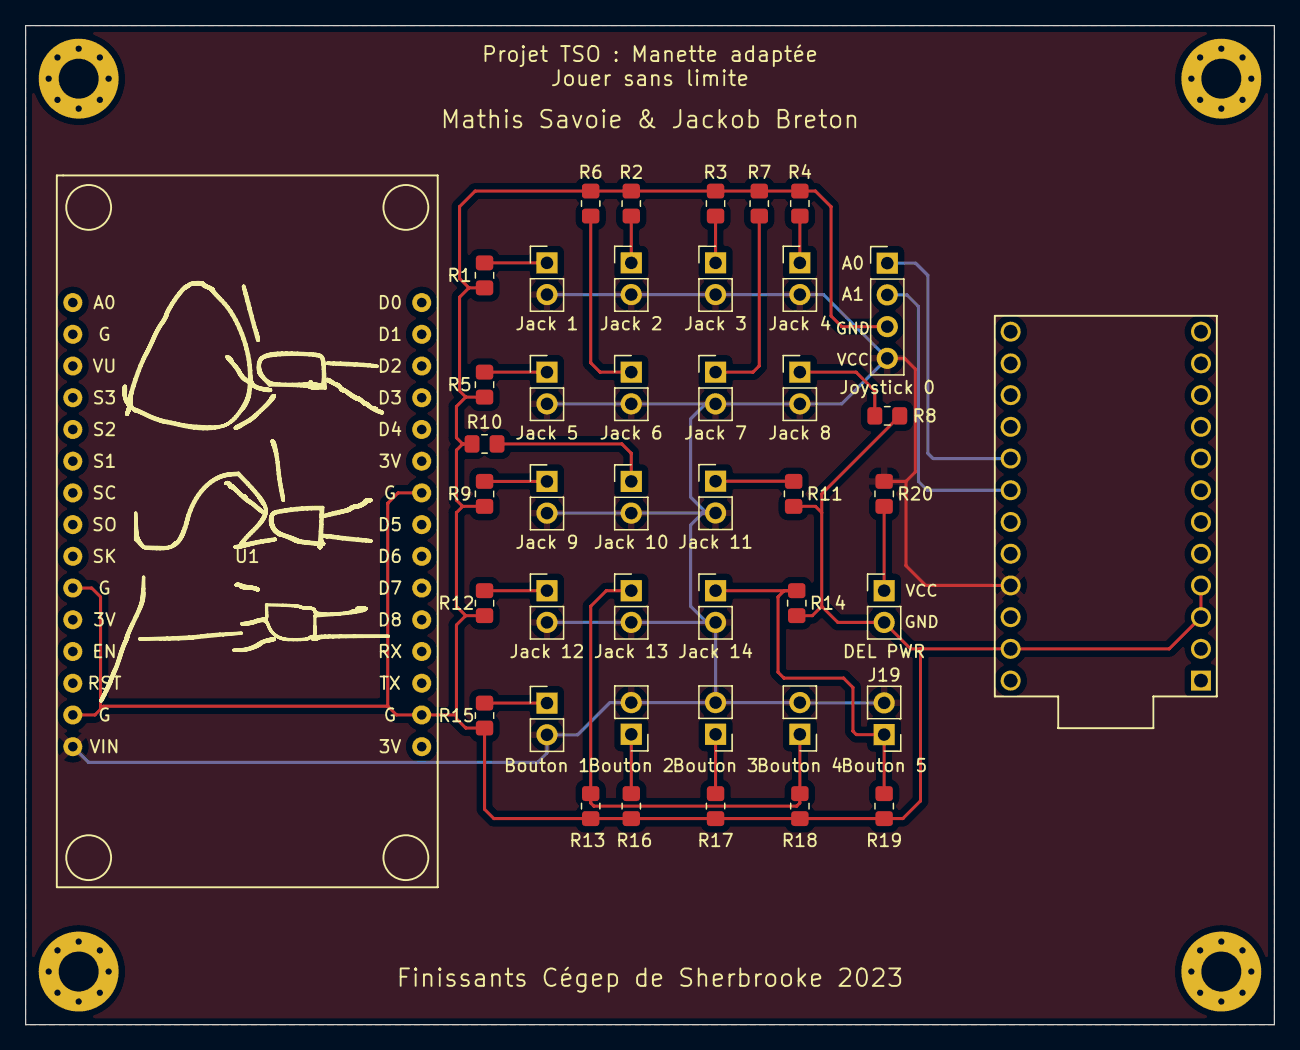
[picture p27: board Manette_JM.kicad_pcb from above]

Board: 4 copper layers, 100.0 x 80.0 mm, 47 parts (0 on the bottom side), 21 nets.

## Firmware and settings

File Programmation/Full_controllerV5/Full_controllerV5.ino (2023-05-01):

/*
  Manette_Adaptée

  Manette de jeux vidéo à l'ordinateur pour les personnes à mobilitées réduites ou ayant un handicap cognitif leur empêchant d'utiliser une manette standard.
  
  Contrôle le curseur d'ordinateur avec un joystick et contrôle différentes touches du clavier et les boutons de la souris avec des boutons
    branchés sur Arduino Pro Micro. Contrôle aussi la réception de JSON arrivant sur son deuxième port série Serial1 pour modifier le
    fonctionnement de ses boutons. Les boutons de la manette sont préconfigurés de manière à ce qu'elle soit déja fonctionnelle pour la 
    plupart des jeux sans utiliser la fonction de configuration externe par JSON. 
    
  Hardware:
  - Arduino Micro Pro.
  - Cable micro USB.
  - 1 à 14 boutons branchés au pattes D2 à D10, D14 à D16, D20 et D21 du Arduino Pro Micro.
  - 1 joystick à 2 axes branché au pattes A0 et A1 du Arduino Pro Micro.
  - 14 résistances de 10K pour chaques entrées de boutons qu'ils soient utilisé ou pas.

  Fonctionnement du joystick: 
    Le programme lit ses entrées analogiques A0 et A1 variants de 0 à 1023 et 
    converti ces valeurs entre -6 et 6. Quand la valeur des deux axes est 0,
    le curseur arrête de bouger et lorsque ces valeurs sont autres que 0 le
    curseur bouge en se basant sur la librairie Mouse.h. 

  Fonctionnement des boutons:
    Avec les entrées digitales configurées en entrées, le programme détecte
    lorsque les boutons sont appuyés et fait un Keyboard.press() de la valeur
    ASCII qui est configuré pour ce bouton. Un Keyboard.release() est ensuite 
    fait lorsque le bouton est relâché pour empêcher que la touche du clavier
    soit encore appuyée. De plus, quand la valeur configuré pour les bouton 
    est en dessous de 5, le programme fait un Mouse.press() du clic gauche (1),
    du clic droit (2) ou du clic du milieu (4) de la souris au lieu d'un 
    Keyboard.press() et puis fait un Mouse.release().

  Fonctionnement de la réception de JSON:
    Le programme détecte lorsque que quelque chose est envoyé sur le port Serial1
    (TX1 et RX1). Il vérifie si c'est un JSON valide et renvoie un message d'erreur 
    sur le port série USB si ce n'en ai pas un. Si le JSON est valide il vérifie si
    c'est une seule configuration qui est reçu ou l'ensemble des configurations de
    boutons. Dans les deux cas, il est séparé et les valeurs décimales sont mises 
    dans les variables des boutons et seront les nouvelles valeurs des boutons. 
    Par exemple, si la nouvelle valeur de la variable "bleu" est 48, le bouton 
    bleu contrôlera la touche "1" du clavier. Ensuite, une fois les configurations
    terminées, le tout est enregistrer dans l'EEPROM et renvoyé sur le port Serial1
    pour confirmer que tout à bien été reçu.

  **IMPORTANT**
    Il faut absoluement télécharger le code WriteEEPROM.ino disponible au 
    https://github.com/Savoie13/Manette_Adaptee/tree/main/Programmation/WriteEEPROM
    dans l'arduino avant de télécharger celui-ci. Sinon, ce code n'optiendra 
    rien quand il essayera d'aller chercher les valeurs de base des boutons dans 
    l'EEPROM et il ne fonctionnera pas. 

  created 12/12/2022
  updated 11/04/2023
  by Mathis Savoie
*/

#include "Mouse.h"            //librairie pour le contrôle du curseur de la souris et ses boutons.
#include "Keyboard.h"         //librairie pour le contrôle du clavier de l'ordinateur.
#include <ArduinoJson.h>      //Librairie pour la réception et le décodage de JSON.
#include <EEPROM.h>           //Librairie pour aller récupérer et enregistrer des données dans l'EEPROM

// Numéros de pattes pour les boutons et le joystick
const int boutonBleu = 16;
const int boutonRouge = 14;
const int boutonVert = 15;
const int boutonBlanc = 20;
const int boutonJaune = 21;
const int boutonJack1 = 2;
const int boutonJack2 = 3;
const int boutonJack3 = 4;
const int boutonJack4 = 5;
const int boutonJack5 = 6;
const int boutonJack6 = 7;
const int boutonJack7 = 8;
const int boutonJack8 = 9;
const int boutonJack9 = 10;
const int xAxis = A0;       // axe X du joystick
const int yAxis = A1;       // axe Y du joystick

//Tableau constant pour l'identification des boutons
const String idBouton[14] = {"b1", "b2", "b3", "b4", "b5", "b6", "b7", "b8", "b9", "b10", "b11", "b12", "b13", "b14"};

// Paramètres pour la lecture du joystick
int range = 12;             // range de valeurs pour le contrôle du curseur
int responseDelay = 5;      // délai de réponse de la souris en ms
int threshold = range / 6;  // seuil du joystick
int center = range / 2;     // valeur du joystick quand il ne bouge pas

//Tableau pour l'état de départ des boutons
int previousButtonState[14] = {HIGH, HIGH, HIGH, HIGH, HIGH, HIGH, HIGH, HIGH, HIGH, HIGH, HIGH, HIGH, HIGH, HIGH};

//Tableau pour contenir les valeurs de chaque boutons
int button[14];

//Tableau pour l'état de départ des boutons
int buttonState[14];

void setup() 
{
  readEEPROM(); //va lire et récupérer les données dans l'EEPROM
  //déclare les boutons en entrée pullup
  pinMode(boutonBleu, INPUT_PULLUP);
  pinMode(boutonRouge, INPUT_PULLUP);
  pinMode(boutonVert, INPUT_PULLUP);
  pinMode(boutonBlanc, INPUT_PULLUP);
  pinMode(boutonJaune, INPUT_PULLUP);
  pinMode(boutonJack1, INPUT_PULLUP);
  pinMode(boutonJack2, INPUT_PULLUP);
  pinMode(boutonJack3, INPUT_PULLUP);
  pinMode(boutonJack4, INPUT_PULLUP);
  pinMode(boutonJack5, INPUT_PULLUP);
  pinMode(boutonJack6, INPUT_PULLUP);
  pinMode(boutonJack7, INPUT_PULLUP);
  pinMode(boutonJack8, INPUT_PULLUP);
  pinMode(boutonJack9, INPUT_PULLUP);
  
  //Prend contrôle de la souris
  Mouse.begin(); 
  //Prend contrôle du Clavier
  Keyboard.begin();
  
  Serial1.begin(115200);        //démarre le port série 1 pour la réception de JSONs
  delay(5000);                //délai de 5 seconde au démarrage de la manette. Aide pour Mouse.h et Keyboard.h
}

void loop() 
{
  // Lit et met à l'échelle les axes
  int xReading = readAxis(A0);
  int yReading = readAxis(A1);
  if(xReading < 0)
    xReading = xReading + 2;  //ajuste le résultat la valeur de l'axe X pour compenser le mauvais potentiomètre

  //vérifie l'état des boutons
  buttonState[0] = digitalRead(boutonBleu);
  buttonState[1] = digitalRead(boutonRouge);
  buttonState[2] = digitalRead(boutonVert);
  buttonState[3] = digitalRead(boutonBlanc);
  buttonState[4] = digitalRead(boutonJaune);
  buttonState[5] = digitalRead(boutonJack1);
  buttonState[6] = digitalRead(boutonJack2);
  buttonState[7] = digitalRead(boutonJack3);
  buttonState[8] = digitalRead(boutonJack4);
  buttonState[9] = digitalRead(boutonJack5);
  buttonState[10] = digitalRead(boutonJack6);
  buttonState[11] = digitalRead(boutonJack7);
  buttonState[12] = digitalRead(boutonJack8);
  buttonState[13] = digitalRead(boutonJack9);

  Mouse.move(xReading, yReading, 0);                  //bouge le curseur en fonction de la position du joystick

  //vérifie tout les boutons pour savoir si ils ont étés appuyés
  for(int i = 0; i < 14; i++)
  {
    if(buttonState[i] == HIGH && previousButtonState[i] == LOW) //si le bouton à été appuyé appuyé
    {
      if(button[i] > 4)   //si c'est un touche du clavier
        Keyboard.press(button[i]);  //appuie sur la touche
      else                //si c'est un bouton de la souris
        Mouse.press(button[i]);     //appuie sur la souris
    }
    if(buttonState[i] == LOW && previousButtonState[i] == HIGH) //si le bouton à été relâché
    {
      if(button[i] > 4)   //si c'est un touche du clavier
        Keyboard.release(button[i]); //relâche la touche du clavier
      else                //si c'est un bouton de la souris
        Mouse.release(button[i]);    //relâche le clic de la souris
    }
  }

  //Enregistre le nouvel état de tous les boutons
  for(int i = 0; i < 14; i++)
  {
    previousButtonState[i] = buttonState[i];
  }
  

  if (Serial1.available())  //si quelque chose est reçu sur le port série 1
  {
    //Lit le JSON et le met dans la variable jsonString
    String jsonString = Serial1.readStringUntil('\n');
    Serial.println(jsonString);
    
    //Alloue un buffer pour l'objet JSON
    StaticJsonDocument<200> doc;
    

    //Sépare le JSON et le met dans le buffer
    DeserializationError error = deserializeJson(doc, jsonString);

    if (error)  //si il n'arrive pas à séparer le JSON
    {
      Serial.println("Error parsing JSON data");    //envoie un message d'erreur sur le port série USB
      return;
    }

    if(jsonString.length() > 30)  //Si le JSON contient toutes les configurations de la manette
    {
      for(int i = 0; i < 14; i++)
      {
        button[i] = doc[String(i + 1)]; //Assigne la nouvelle valeur à tout les boutons
      }
    }
    else                          //Si le JSON ne contient qu'une seule nouvelle configuration pour la manette
    {
      int id = doc["id"];         //Enregistre quel bouton est changé
      int valeur = doc["valeur"]; //Enregistre la valeur de ce bouton
      
      for(int i = 0; i < 14; i++) //Passe à travers tout les boutons
      {
        if(i + 1 == id)           //Si c'est le boutons qui doit être changé
        {
          button[i] = valeur;     //On lui assigne sa nouvelle configuration
        }
      }
    }

    

    sendJSONConfig();             //Renvoie les nouvelles configurations de la manette sur le port Serial1
    
    writeEEPROM();                //Enregistre les nouvelles configurations de la manette sur l'EEPROM
  }
  
  delay(responseDelay);   //délai de réponse de la souris
}


/*
  Lit un axe (A0 ou A1 pour X ou Y) et le met à l'échelle selon la variable "range" au début du code
*/
int readAxis(int thisAxis) 
{
  // Lit l'entrée analogique
  int reading = analogRead(thisAxis);

  //Met la donnée 0 à 1023 à l'échelle selon "range"
  reading = map(reading, 0, 1023, 0, range);

  //S'assure que la position initiale du Joystick est 0
  int distance = reading - center;
  
  distance = distance * -1; //inverse les axes parce que le joystick est à l'envers

  if(distance < 0)            
    distance = distance - 2;  //ajuste les valeurs pour compenser le mauvais potentiomètre

  //Met un buffer sur lequel le curseur ne bougera pas et restera a zero
  if (abs(distance) < threshold)
    distance = 0;
    
  //Retourne la distance entre -6 et 6 pour faire bouger le curseur
  return distance;
}

/*
  Lit les valeurs enregistrées dans l'EEPROM et assigne ces valeurs à tout les boutons. Elle sert surtout
  au début du code pour aller chercher les valeurs qui étaient assignées lors de la dernière utilisation
  de la manette.
*/
void readEEPROM()
{
  for(int i = 0; i < 14; i++)
  {
    button[i] = EEPROM.read(i);
  }
  return;
}

/*
  Écrit les valeurs des boutons dans l'EEPROM de l'Arduino pour que ces valeurs soient reprises lorsqu'on redémarre
  la manette. Cette fonction est utilisé à chaque fois qu'on change une configuration de la manette.
*/
void writeEEPROM()
{
  for(int i = 0; i < 14; i++)
  {
    EEPROM.write(i, button[i]);
  }
  return;
}

/*
  Met les configurations des boutons dans un JSON et les envoies sur le port Serial1 pour qu'elles puissent être reçues 
  par le NodeMCU ESP8266 et êtres affichées sur le site WEB.
*/
void sendJSONConfig()
{
  //Alloue un buffer pour l'objet JSON
  StaticJsonDocument<512> docRetour;

  for(int i = 0; i < 14; i++)
  {  
    docRetour[idBouton[i]] = button[i];
  }
  
  /*for(int i = 0; i < 14; i++)
  {   
    if(button[i] > 32 && button[i] < 128) //si la valeur du boutons est un simple caractère ASCCI
    {
      char convertC = button[i];          //la converti en charactère
      String convertS = String(convertC); //la converti en String
      docRetour[idBouton[i]] = convertS;  //la met dans le JSON
    }
    else                                //Si la valeur est un caractètre spécial ou un clic de souris
    {
      //on lui assigne sa valeur de manière lisible au lieu d'un chiffre
      switch(button[i])
      {
        case 1:
          docRetour[idBouton[i]] = "Clic Gauche";
          break;
        case 2:
          docRetour[idBouton[i]] = "Clic Droit";
          break;
        case 4:
          docRetour[idBouton[i]] = "Clic Milieu";
          break;
        case 13:
          docRetour[idBouton[i]] = "ENTER";
          break;
        case 27:
          docRetour[idBouton[i]] = "ESC";
          break;
        case 32:
          docRetour[idBouton[i]] = "ESPACE";
          break;
        case 128:
          docRetour[idBouton[i]] = "Ctrl";
          break;
        case 129:
          docRetour[idBouton[i]] = "Shift";
          break;
        case 178:
          docRetour[idBouton[i]] = "Backspace";
          break;
        case 179:
          docRetour[idBouton[i]] = "Tab";
          break;
        case 193:
          docRetour[idBouton[i]] = "Caps Lock";
          break;
        case 215:
          docRetour[idBouton[i]] = "Flèche droite";
          break;
        case 216:
          docRetour[idBouton[i]] = "Flèche gauche";
          break;
        case 217:
          docRetour[idBouton[i]] = "Flèche bas";
          break;
        case 218:
          docRetour[idBouton[i]] = "Flèche haut";
          break;
        default:
          break;
      }
      
    }
      
  }*/

    
  serializeJson(docRetour, Serial1);  //Sérialise le JSON et l'envoie sur le port Serial1
  Serial1.print("\n");                //Ajoute un "\n" pour identifier la fin du JSON 
}

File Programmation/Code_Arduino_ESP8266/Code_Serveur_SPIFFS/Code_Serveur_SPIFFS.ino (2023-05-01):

/*
 * Ce code est destiné à être utilisé avec une carte ESP8266 pour créer un point d'accès Wi-Fi qui peut être utilisé pour contrôler un appareil 
 * à distance. Le code utilise plusieurs bibliothèques, notamment la bibliothèque ESPAsyncTCP pour la communication asynchrone avec TCP/IP, la 
 * bibliothèque ESPAsyncWebServer pour créer un serveur web asynchrone, la bibliothèque FS pour manipuler le système de fichiers de la carte 
 * ESP8266, la bibliothèque Wire pour communiquer avec des périphériques via I2C, la bibliothèque WebSocketsServer pour la communication asynchrone 
 * via WebSockets et la bibliothèque DNSServer pour utiliser le serveur DNS.
 * 
 * Le code utilise également une instance de DNSServer pour gérer les requêtes DNS, une instance de WebSocket pour gérer les connexions WebSocket, une 
 * instance de serveur web pour écouter les requêtes sur le port 80 et une instance d'EventSource pour envoyer des événements.
 * 
 * Le code utilise une classe pour gérer le portail captif et une fonction pour configurer le serveur web. Il utilise également une fonction pour envoyer 
 * les messages reçus en "WebSocket" vers la patte TX de l'ESP8266 afin de l'envoyer vers l'Arduino Pro Micro.
 * 
 * Enfin, le code vérifie l'état du WebSocket en fonction du type d'événement envoyé par le serveur en WebSocket, notamment WS_EVT_DATA pour envoyer 
 * les messages vers la patte TX et WS_EVT_DISCONNECTED pour fermer la connexion.
 */
 
#include <ESP8266WiFi.h> // Bibliothèque pour utiliser la fonctionnalité WiFi de la carte ESP8266
#include <ESPAsyncTCP.h> // Bibliothèque pour utiliser la communication asynchrone avec TCP/IP
#include <ESPAsyncWebServer.h> // Bibliothèque pour utiliser un serveur web asynchrone
#include "FS.h" // Bibliothèque pour manipuler le système de fichiers de la carte ESP8266
#include <Wire.h> // Bibliothèque pour communiquer avec des périphériques via I2C
#include <WebSocketsServer.h> // Bibliothèque pour utiliser la communication asynchrone via WebSockets
#include <DNSServer.h> // Bibliothèque pour utiliser le serveur DNS

const byte DNS_PORT = 53; // Numéro de port utilisé par le serveur DNS
DNSServer dnsServer; // Instance de DNSServer pour gérer les requêtes DNS
AsyncWebSocket ws("/ws"); // Instance de WebSocket pour gérer les connexions WebSocket
AsyncWebServer server(80); // Instance de serveur web pour écouter les requêtes sur le port 80
AsyncEventSource events("/events"); // Instance d'EventSource pour envoyer des événements

char jsonData = 0; // Variable pour stocker les données reçues depuis le port série

/*
 * Classe: CaptiveRequestHandler
 * Héritage: public AsyncWebHandler
 * Méthodes:
 * canHandle(AsyncWebServerRequest *request) : bool
 * handleRequest(AsyncWebServerRequest *request) : void
 * 
 * Description: Cette classe est utilisée pour gérer les requêtes d'un serveur web asynchrone. Elle hérite de la classe 
 * AsyncWebHandler et implémente les méthodes canHandle et handleRequest. La méthode canHandle vérifie si l'URL de la requête 
 * est "/ws", et la méthode handleRequest envoie le fichier "index.html" en réponse à la requête.
 */
class CaptiveRequestHandler : public AsyncWebHandler {
public:
  CaptiveRequestHandler() {}
  virtual ~CaptiveRequestHandler() {}

  bool canHandle(AsyncWebServerRequest *request)
  {
    if(request->url() == "/ws") // Si l'URL de la requête est "/ws"
      return false;
    return true;
  }

  void handleRequest(AsyncWebServerRequest *request) {
    request->send(SPIFFS, "/index.html","text/html", false); // Envoie le fichier "index.html" en réponse à la requête
  }
};

/*
 * Cette fonction "setupServer" configure un serveur web et définit les chemins qui envoient des fichiers en réponse à des requêtes HTTP_GET. Plus précisément :
 * 
 * Le chemin "/" envoie le fichier "index.html" en réponse à une requête HTTP_GET, et affiche "Client Connected" dans le terminal.
 * Le chemin "/commands.js" envoie le fichier "commands.js" en réponse à une requête HTTP_GET.
 * Le chemin "/bootstrap.css" envoie le fichier "bootstrap.css" en réponse à une requête HTTP_GET.
 * Le chemin "/manette.png" envoie une image au format "x-icon" en réponse à une requête HTTP_GET.
 */
void setupServer(){

  // Chemin qui envoie le fichier index.html lorsque le serveur envoie une requête HTTP_GET
  server.on("/", HTTP_GET, [](AsyncWebServerRequest *request){
  request->send(SPIFFS, "/index.html","text/html", false);
  Serial.println("Client Connected"); // Affiche dans le terminal que le client est connecté
  });

  // Chemin qui envoie le fichier JavaScript lorsque le serveur envoie une requête HTTP_GET
  server.on("/commands.js", HTTP_GET, [](AsyncWebServerRequest *request){
  request->send(SPIFFS, "/commands.js", "text/js");
  });

  // Chemin qui envoie le fichier bootstrap.css lorsque le serveur envoie une requête HTTP_GET
  server.on("/bootstrap.css", HTTP_GET, [](AsyncWebServerRequest *request){
  request->send(SPIFFS, "/bootstrap.css", "text/css");
  });

  // Chemin qui envoie une image(icon) lorsque le serveur envoie une requête HTTP_GET
  server.on("/manette.png", HTTP_GET, [](AsyncWebServerRequest *request){
  request->send(SPIFFS, "/manette.png", "image/x-icon");
  });
}

/*
 * Cette méthode "setup" initialise les composants nécessaires pour la mise en place d'un point d'accès WiFi à l'aide d'un ESP8266. 
 * Elle configure le "baud rate" de la communication série à 115200, démarre le montage SPIFFS pour stocker les fichiers du site web, 
 * configure le point d'accès WiFi de l'ESP8266, affiche l'adresse IP dans le terminal, initialise le serveur web asynchrone, démarre 
 * le serveur DNS pour le portail captif, lance le portail captif, initialise la communication Websocket et démarre le serveur web.
 */
void setup(){
  Serial.begin(115200); // préréglage du "baud rate" à 115200
   
  if(!SPIFFS.begin()){ // si le montage SPIFFS à une erreur...
    Serial.println("Une erreur est survenue lors du montage SPIFFS");
    return;
  }
  
  Serial.println("Configuration en mode point d'accès");
  WiFi.mode(WIFI_AP); // met le WiFi de l'ESP8266 en point d'accès
  WiFi.softAP("Wifi_Manette"); // renomme le point d'accès pour "Wifi_Manette"
  
  Serial.print("AP IP address: "); // Montre ce message avant l'IP dans le terminal
  Serial.println(WiFi.softAPIP()); // Montre l'adresse IP dans le terminal
  Serial.println("Setting up Async WebServer"); // Affiche le commencement du setup du serveur
  setupServer();
  
  //Serial.println("Démarrage du serveur DNS");
  dnsServer.start(DNS_PORT, "*", WiFi.softAPIP()); // démarre le serveur DNS pour le portail captif
  server.addHandler(new CaptiveRequestHandler()).setFilter(ON_AP_FILTER); // envoie une requête pour lancé le portail captif

  initWebSocket();

  server.begin(); // démarre le serveur
  //Serial.println("Site Web prêt à l'utilisation !");
}
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

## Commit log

2023-01-19 Add docu
    [247-575-SH_GANTT_projet.xlsx]
2023-01-24 KiCad V1 Manette
    [Manette_JM.kicad_pcb, Manette_JM.kicad_sch]
2023-01-26 Schéma électrique et début PCB
    [Manette_JM.kicad_pcb, Manette_JM.kicad_sch]
2023-01-31 Quick changes
    modification code et schéma
    [Manette_JM.kicad_sch]
2023-01-31 PCB upgrade
    [Manette_JM.kicad_pcb, Manette_JM.kicad_sch]
2023-02-03 PCB changes
    [Manette_JM.kicad_pcb, Manette_JM.kicad_sch]
2023-02-06 Create Pieces_commande.xlsx
    Pièces à commander
    [Pieces_commande.xlsx]
2023-02-06 quick chanfes
    [Manette_JM.kicad_pcb, Manette_JM.kicad_sch]
2023-02-06 quick pcb changes
    [Manette_JM-B_Cu.gbr, Manette_JM-B_Mask.gbr, Manette_JM-B_Silkscreen.gbr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]
2023-02-20 Quick PCB change
    corrigé une faute d'orthographe
    [Manette_JM.kicad_pcb]
2023-02-20 Update Full_controllerV4.ino
    finis les commentaires du programme
2023-03-27 Version plus propre du répertoire de l'ESP8266
    Beaucoup de changement dans le répertoire. J'ai ajouté les nouveaux fichiers et j'ai retiré les anciens. J'ai aussi ajouter des read.me
2023-03-27 update
    j'ai commenté le code de Full_controllerV5 et j'ai avancé le manuel technique
2023-03-27 Ajout d'un README.md
    Commentaires ajoutés afin de faciliter la compréhension.
2023-03-27 Ajout de Read.me dans les dossier de programmation
2023-03-28 reorder
    replacé les fichiers du dossier de programmatiion
2023-04-11 Update manuel_technique_manette_adaptée.docx
    J'ai mis la dernière version du manuel technique sur le Git
2023-04-20 ajout du nouveau joystick
    Manche de joystick pour le nouveau joystick que nous avons installé
2023-04-25 changements rapides des codes
2023-04-27 Update Full_controllerV5.ino
    J'ai ajouté une ligne que j'avais oublié
2023-05-01 Changement code ESP
    Nous avons ajouté la nouvelle façon de programmer l'ESP8266 et nous avons mis l'ancienne version dans "old versions"
2023-05-04 Nettoyage et changement
    Changement de descriptions et de fichiers. Le GitHub est maintenant plus propre.
    [Joystick_VFinale.stl]
2023-05-09 quelques modifications pour le style
    style de la page web
